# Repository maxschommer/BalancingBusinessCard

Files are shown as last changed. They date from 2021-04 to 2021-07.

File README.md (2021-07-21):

# business card

This is a persistence-of-vision (POV) business card, which is also NFC enabled
to aid in sharing contact information. POV is enabled by an accelerometer which
detects the end points of a swing of the card made by the user, and arranges
the letters to flash at the correct time in between two estimated end points
(the future end-point is guessed at by the length of the previous swing). Settings are changed by a capacitive sense button.

# Directory Structure

The firmare of the card is located in the `src` directory. The electrical
design files are in `design/business_card`. Images and other media are inside
`media`.

- [src](src/)
  - Contains the firmware of the card
- [design](design/)
  - Contains the KiCAD design files of the board
- [card_manufacturing](card_manufacturing/)
  - Contains python scripts used to generate GCODE to laser etch the aluminum top of the card.
- [media](media/)
  - Contains media (gifs, images, etc.)

# Building and Flashing Firmware

In order to flash the firmware, you must have the AVR toolchain installed.

`sudo apt-get install binutils gcc-avr avr-libc uisp avrdude flex byacc bison`

Then, navigate to the `src` directory and run `make` to build the object
file. In order to flash a business card, make sure to have your AVR programmer
plugged into your computer and connected to the board (and make sure the board
is appropriately powered!), then run

`make flash`

avrdude should say the the flash was successfull.

# Running manufacturing scripts

Some helper scripts exist to automate a lot of the manufacturing process for
customization. The scripts are specific to GRBL capable CNC machines (which
can laser etch). Scripts are written in python, and can be installed by
downloading the repository and running:

`pip install -e .`

Once the dependencies are installed, the scripts can be run from the root
directory, for example:

`python -m card_manufacturing.gcode_streamer`

## image_to_laser

This is a command line argument script which converts an image to an efficiently
rastered laser etcher GCODE path. It makes sure to utilize [laser mode](https://github.com/gnea/grbl/wiki/Grbl-v1.1-Laser-Mode) which
has been implemented in GRBL v1.1. The image is thresholded and the laser path
is binary (since the etching is all or nothing on coated aluminum). To get the
help for the script run:

`python -m card_manufacturing.image_to_laser -h`

## laser_calibration

This script generates a GCODE path to calibrate a CNC (with Z travel) with a
laser attachment. It progressively creates lines at different Z levels and
marks what the Z difference was on the line, so the user can identify the line
with the best marking and apply the appropriate offset for future etches. To
get the help for the script run:

`python -m card_manufacturing.laser_calibration -h`

## gcode_streamer

Finally, once GCODE is generated, the following script will stream the GCODE
to the CNC to run the part. To get the help for the script run:

`python -m card_manufacturing.gcode_streamer -h`

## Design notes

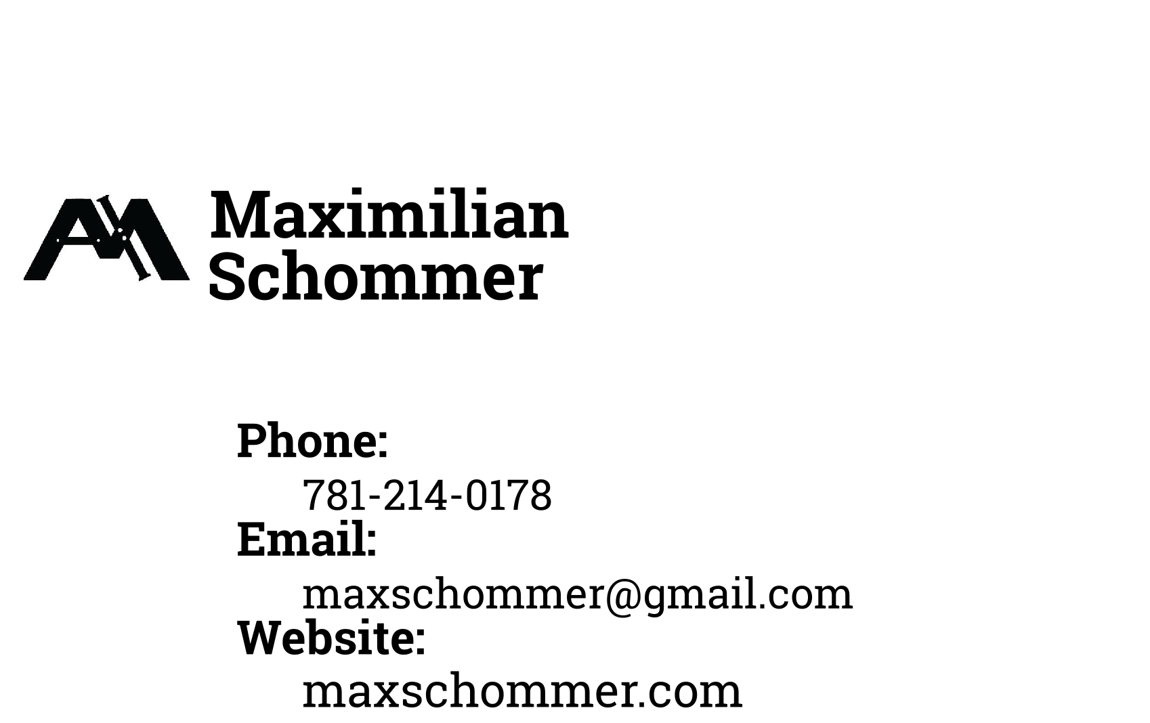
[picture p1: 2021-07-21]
media/max_card_laser.png

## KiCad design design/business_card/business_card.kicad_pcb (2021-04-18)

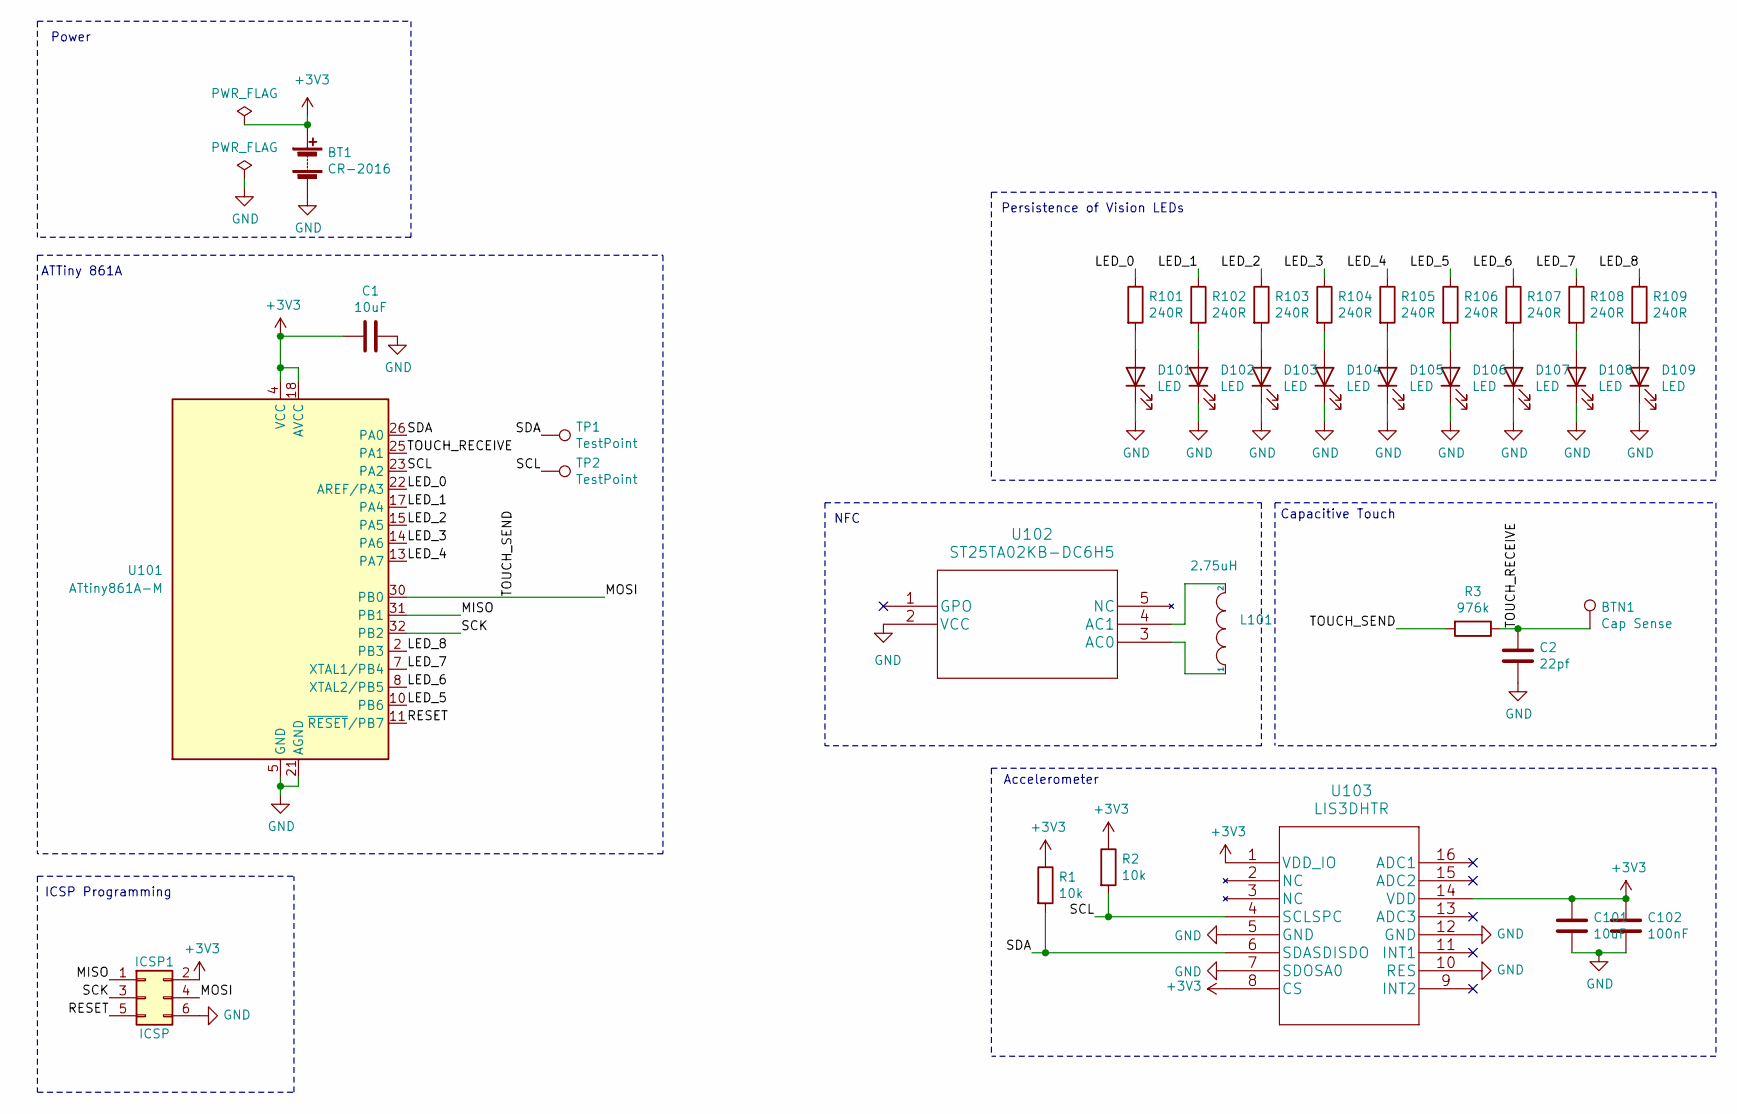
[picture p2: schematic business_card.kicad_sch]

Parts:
BT1: CR-2016; CR2016VP
BTN1: Cap Sense; CAP_TOUCH
C1, C101: 10uF; C_0805_2012Metric; Digikey 1276-6456-1-ND
C2: 22pf; C_0603_1608Metric; Digikey 732-7762-1-ND
C102: 100nF; C_0603_1608Metric; Digikey 311-1779-1-ND
D101, D102, D103, D104, D105, D106, D107, D108, D109: LED; LED_0603_1608Metric; Digikey 160-1183-1-ND
ICSP1: ICSP; PinHeader_2x03_P2.54mm_Vertical
L101: 2.75uH; Trace_Inductor_2_75uH
R1, R2: 10k; R_0603_1608Metric; Digikey 311-10KGRCT-ND
R3: 976k; R_0603_1608Metric; Digikey 311-976KHRCT-ND
R101, R102, R103, R104, R105, R106, R107, R108, R109: 240R; R_0603_1608Metric; Digikey 311-240GRCT-ND
TP1, TP2: TestPoint; TestPoint_Pad_D1.0mm
U101: ATtiny861A-M; QFN-32-1EP_5x5mm_P0.5mm_EP3.1x3.1mm; Digikey ATTINY861-15MZCT-ND
U102: ST25TA02KB-DC6H5; Digikey 497-19639-1-ND
U103: LIS3DHTR; Digikey 497-10613-1-ND

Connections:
+3V3: BT1.1 (+), C1.1, C101.1, C102.1, ICSP1.2, R1.1, R2.1, U101.4 (VCC), U101.18 (AVCC), U103.1 (VDD_IO), U103.8 (CS), U103.14 (VDD)
/LED_0: R101.1, U101.22 (AREF/PA3)
/LED_1: R102.1, U101.17 (PA4)
/LED_2: R103.1, U101.15 (PA5)
/LED_3: R104.1, U101.14 (PA6)
/LED_4: R105.1, U101.13 (PA7)
/LED_5: R106.1, U101.10 (PB6)
/LED_6: R107.1, U101.8 (XTAL2/PB5)
/LED_7: R108.1, U101.7 (XTAL1/PB4)
/LED_8: R109.1, U101.2 (PB3)
/MISO: ICSP1.1, U101.31 (PB1)
/MOSI: ICSP1.4, R3.2, U101.30 (PB0)
/RESET: ICSP1.5, U101.11 (~RESET~/PB7)
/SCK: ICSP1.3, U101.32 (PB2)
/SCL: R2.2, TP2.1, U101.23 (PA2), U103.4 (SCLSPC)
/SDA: R1.2, TP1.1, U101.26 (PA0), U103.6 (SDASDISDO)
/TOUCH_RECEIVE: BTN1.1, C2.1, R3.1, U101.25 (PA1)
GND: BT1.2 (-), C1.2, C2.2, C101.2, C102.2, D101.1 (K), D102.1 (K), D103.1 (K), D104.1 (K), D105.1 (K), D106.1 (K), D107.1 (K), D108.1 (K), D109.1 (K), ICSP1.6, U101.5 (GND), U101.21 (AGND), U101.33 (GND), U102.2 (VCC), U103.5 (GND), U103.7 (SDOSA0), U103.10 (RES), U103.12 (GND)
unnamed: D101.2 (A), R101.2
unnamed: D102.2 (A), R102.2
unnamed: D103.2 (A), R103.2
unnamed: D104.2 (A), R104.2
unnamed: D105.2 (A), R105.2
unnamed: D106.2 (A), R106.2
unnamed: D107.2 (A), R107.2
unnamed: D108.2 (A), R108.2
unnamed: D109.2 (A), R109.2
unnamed: L101.1, U102.3 (AC0)
unnamed: L101.2, U102.4 (AC1)

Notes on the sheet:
Power
ATTiny 861A
ICSP Programming
NFC
Accelerometer
Persistence of Vision LEDs
Capacitive Touch

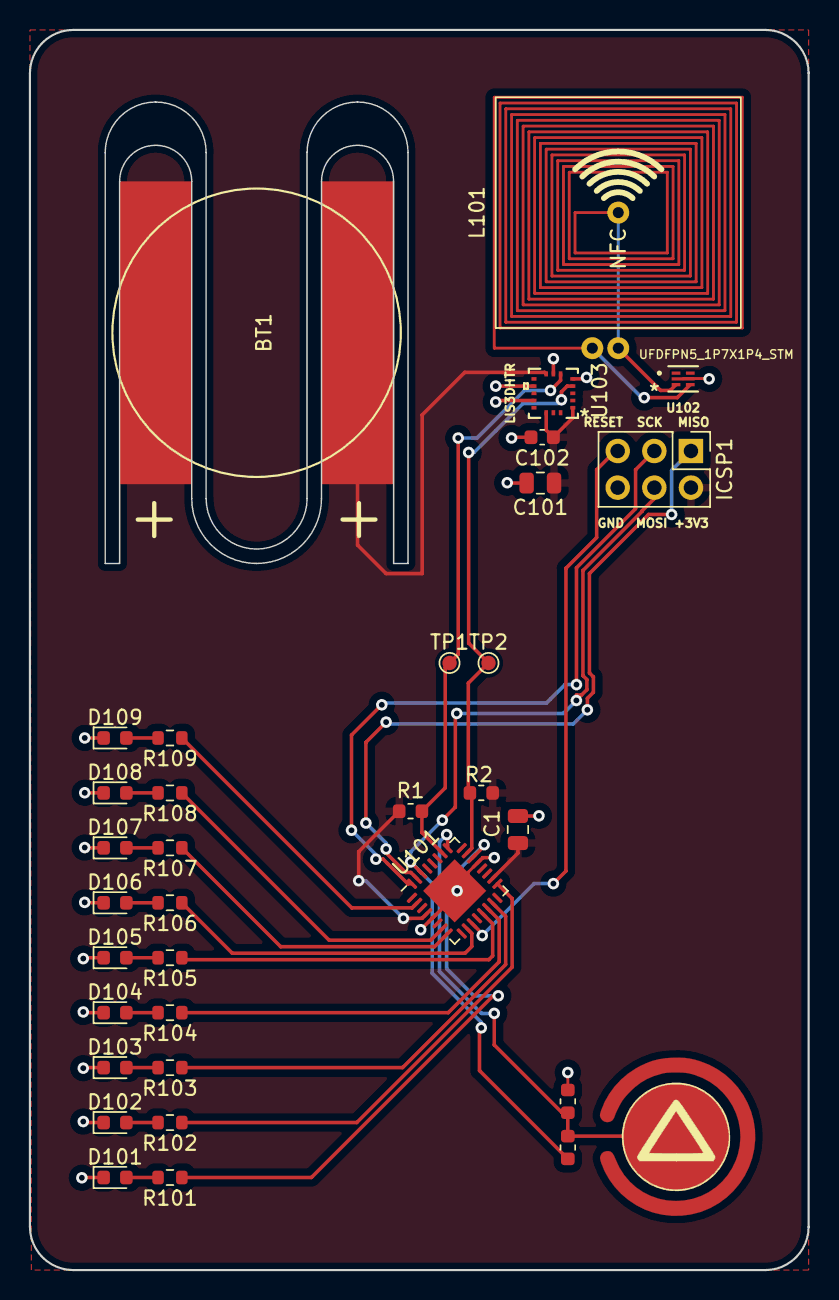
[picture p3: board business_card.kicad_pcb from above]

Board: 2 copper layers, 54.0 x 86.0 mm, 34 parts (0 on the bottom side), 29 nets.

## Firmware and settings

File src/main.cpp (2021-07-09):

/*
 * BalancingBusinessCard.cpp
 *
 * Created: 11/3/2018 4:36:13 PM
 * Author : mschommer
 */
#define F_CPU 2000000UL // 2 MHz for delay

#include <avr/io.h>
#include <stdio.h>
#include <math.h>
#include <util/delay.h>
#include <avr/interrupt.h>

#include "TinyWireM.h"
#include "USI_TWI_Master.h"

#include "alphabet.h"
#include "accelerometer_utils.h"
#include "touch_utils.h"

void Init_ACC()
{												   // Setup the LIS3DHTR
	lis3dhWriteByte(LIS3DH_CTRL_REG1, 0b10010111); // 1.344 kHz , No Low-power mode, all axes enabled
	lis3dhWriteByte(LIS3DH_CTRL_REG4, 0b00110000); // +-16g range, defaults otherwise
}

// Gets the current x-axis acceleration in m/s
float read_accel()
{
	int8_t raw = lis3dhReadByte(LIS3DH_OUT_X_H);
	return (int16_t(raw) << 2) * 0.004 * 9.8 * 8; // 4 milligees per digit in +-2g mode
}

void ShowLine(uint16_t line)
{
	PORTA = (PORTA & (~(0b000011111 << 3))) | (line & 0b000011111) << 3; // LED0, LED1, LED2, LED3, LED4
	PORTB = (PORTB & (~0b01111000)) |									 // Preserve TOUCH_SEND
			((line & 0b000100000) << 1) |								 // LED5
			((line & 0b001000000) >> 1) |								 // LED6
			((line & 0b010000000) >> 3) |								 // LED7
			((line & 0b100000000) >> 5);								 // LED8
}

// current_time returns the current time in increments of about 0.1 ms (1 tick), 0.000128s for 2MHz clock
// Must be called at least 30 times per second, or could lose count.
uint32_t current_time()
{
	static uint32_t timerOverflowCount = 0; // Each overflow count is 0.032768s for 2MHz clock

	// Record total time since start
	if ((TIFR & (1 << TOV0)) == (1 << TOV0)) // check if overflow flag is set
	{
		TIFR = 1 << TOV0; //clear timer1 overflow flag
		timerOverflowCount++;
	}
	return TCNT0L + 256 * timerOverflowCount; // total time since start of uC
}

// Returns 1 if maxima detected, -1 if minima detected, or 0
int8_t detect_edge(uint32_t t)
{
	// TODO: switch to a filter?
	const float DEBOUNCE_THRESH = 4.0; // m/s^2

	static int8_t dir = 1; // Start looking for a max

	static float min_detected = 9999999;

	float val = read_accel() * dir;

	if (val < min_detected)
	{
		min_detected = val;
	}

	if (val > min_detected + DEBOUNCE_THRESH)
	{
		// Edge detected
		min_detected = 9999999;
		dir *= -1;
		return dir;
	}

	return 0;
}

int main()
{
	// Configuring ATTiny

	CLKPR = 1 << CLKPCE;
	CLKPR = 1 << CLKPS1; // Set clock division to 4

	TCCR0B = 1 << CS02; // Divide clock by 256

	USICR = 1 << USIWM1; // Enable Two-Wire mode of USI register

	DDRB = 0b01111011; // Set LEDs on port B as output, and the touch send PB0
	DDRA = 0b11111000; // Set LEDs on port A as output
	TinyWireM.begin(); // initialize I2C lib

	Init_ACC();

	// Message Display Parameters
	char *messages[2];
	messages[0] = "MAX";
	messages[1] = "ERIC";

	int message_idx = 0;
	char *message = messages[message_idx];                  // Message to display
	int kerning = 2;					// Space between letters, in bars
	const float before_message_frac = 0.2;                  // Target fraction of cycle waiting before display

	// Generate Flash Pattern
	FlashPattern flashPattern;
	convertString(message, kerning, &flashPattern);
	long double timeToWait;

	// Variable Initializations
	uint32_t lastLeftEdgeTime = current_time();             // Time that the last acceleration peak was detected
	uint32_t estimated_period = 10000;			// In ticks, time to sweep right
	uint32_t message_start_time = 0;
	uint32_t message_end_time = 1;
	uint32_t message_duration = 1;
	int8_t dir = 1; // 1 if moving right, -1 if moving left

	TouchSense touch;
	touch.threshold = 10;

	while (1)
	{
		// Detect the left edge
		uint32_t t = current_time();

		float frac_message = (t - message_start_time) / float(message_end_time - message_start_time);

		// Display
		if (frac_message >= 0.0 && frac_message < 1.0)
		{
			size_t currentIndex = frac_message * flashPattern.length;

			if (dir > 0)
			{
				currentIndex = flashPattern.length - currentIndex - 1;
			}

			ShowLine(flashPattern.data[currentIndex]);
		}
		else
		{
			ShowLine(0);

			// Check for and handle a button press
			if (touch.just_pressed())
			{
				int ms = 0;
				while (ms < 1000){
					ShowLine(message_idx);
					_delay_ms(10);
					ms += 10;
					if (touch.just_pressed()){
						message_idx++;
						ms = 0;
					}
				}
				message = messages[message_idx % (sizeof(messages) / sizeof(messages[0]))];
				convertString(message, kerning, &flashPattern);
			}

			// Check for an edge, update variables if found
			int8_t edge = detect_edge(t);

			if (edge == -1)
			{
				// Detected a left edge
				dir = edge;
				lastLeftEdgeTime = t;

				message_start_time = lastLeftEdgeTime + (estimated_period * before_message_frac);
				message_end_time = lastLeftEdgeTime + (estimated_period * (1 - before_message_frac));
				message_duration = message_end_time - message_start_time;
			}
			else if (edge == 1)
			{
				// Detected a right edge
				dir = edge;

				// Estimate the period
				estimated_period = t - lastLeftEdgeTime;
				if (estimated_period > 10000)
				{
					estimated_period = 10000;
				}

				uint32_t detected_delay = t - message_end_time;
				if (detected_delay > 10000 || detected_delay < 0)
				{
					// Do not display a message
					message_start_time = 0;
					message_end_time = 1;
				}
				else
				{
					message_start_time = t + detected_delay;
					message_end_time = message_start_time + message_duration;
				}
			}
		}
	}
}

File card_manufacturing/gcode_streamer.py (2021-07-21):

import time
from typing import List
from functools import partial
import signal
import sys
import re
import argparse
from pathlib import Path
import logging
import plac
import serial

# Uncomment the line below to mock the serial port
# import card_manufacturing.fake_serial as serial

RX_BUFFER_SIZE = 128


# Global variables
g_consumed = 0
g_error = 0
g_sent = 0
g_buffer: List[int] = []
is_absolute = False


def clean(conn: serial.Serial):
    """Clean the serial port from 

    Args:
        conn (serial.Serial): The serial connection to clean.
    """
    global g_consumed
    global g_error
    global g_sent
    global g_buffer
    while g_sent > g_consumed:
        grbl_resp = conn.readline().strip().decode()
        # Debug response
        if grbl_resp.find('ok') < 0 and grbl_resp.find('error') < 0:
            logging.info(f"MSG: '{grbl_resp}'")
        else:  # Interpreted GCode response
            if grbl_resp.find('error') >= 0:
                logging.warning(f"GCode Error: {grbl_resp}")
                g_error += 1
            g_consumed += 1
            logging.info(f"REC<{g_consumed}: '{grbl_resp}'")
            del g_buffer[0]


def send_and_log(conn, data):
    if isinstance(data, str):
        data = data.encode()
    global g_consumed
    conn.write(data)
    resp = conn.readline().decode()
    logging.info(f"REC<{g_consumed}: '{resp}'")


def signal_handler(conn, signal, frame):
    global g_consumed
    global g_error
    global g_sent
    global is_absolute
    clean(conn)

    logging.info("Returning Home")
    if not is_absolute:
        send_and_log(conn, "G90\n".encode())
    send_and_log(conn, "G0X0Y0Z0\n".encode())
    send_and_log(conn, "M5\n")
    send_and_log(conn, "$32=0\n")
    sys.exit(0)


@plac.pos('file', 'the gcode file to stream', type=Path)
@plac.annotations(
    device_file=(
        'the serial device path'
    ),
    baud_rate=(
        'the baud rate of the device to stream to',
        'option', 'br', int),
    zero_cnc=(
        'zero the CNC to cut from it\'s current position.',
        'flag', 'zc'
    ),
    log_level=(
        'the log level for the program. Options are "DEBUG",'
        '"INFO", "WARNING", "ERROR", and "CRITICAL".', 'option',
        'll', str, ["DEBUG", "INFO", "WARNING", "ERROR",
                    "CRITICAL"])
)
def gcode_streamer(
    file: Path,
    device_file: str,
    baud_rate: int = 115200,
    zero_cnc: bool = False,
    log_level: str = "INFO"
):
    """Stream GCODE to a GRBL device using an aggressive streaming protocol
    which attempts to keep the buffer on the machine as full as possible.
    """
    global g_consumed
    global g_error
    global g_sent
    global g_buffer
    global is_absolute
    logging.basicConfig()
    logging.getLogger().setLevel(log_level)

    with serial.Serial(device_file, baud_rate) as s_conn:
        signal.signal(signal.SIGINT, partial(signal_handler, s_conn))

        logging.info("Initializing grbl")
        s_conn.write("\r\n\r\n".encode())
        resp = s_conn.readline()

        time.sleep(2)
        s_conn.flushInput()
        s_conn.write("$X\n".encode())
        resp = s_conn.readline().strip().decode()
        logging.info(f"Unlocked: {resp}")

        if zero_cnc:
            send_and_log(s_conn, "G92X0Y0Z0\n")
            send_and_log(s_conn, "G10L20P1X0Y0Z0\n")
            logging.info(f"Zeroed: {resp}")

        t_start = time.time()
        with open(file, mode='r') as f:

            for i, line in enumerate(f):
                line = re.sub('\s|\(.*?\)', '', line).upper()

                g_buffer.append(len(line))

                # If the buffer is full, wait for a response
                while sum(g_buffer) >= RX_BUFFER_SIZE - 1 | s_conn.inWaiting():
                    grbl_resp = s_conn.readline().strip().decode()

                    # Debug response
                    if grbl_resp.find('ok') < 0 and grbl_resp.find('error') < 0:
                        logging.info(f"MSG: '{grbl_resp}'")
                    else:  # Interpreted GCode response
                        if grbl_resp.find('error') >= 0:
                            logging.warning(f"GCode Error: {grbl_resp}")
                            g_error += 1
                        g_consumed += 1
                        logging.info(f"REC<{g_consumed}: '{grbl_resp}'")
                        del g_buffer[0]

                s_conn.write(f'{line}\n'.encode())
                if line.find('G90') >= 0:
                    is_absolute = True
                if line.find('G91') >= 0:
                    is_absolute = False
                g_sent = i
                logging.info(f"SND>{i}: '{line}'")

            clean(s_conn)

        # We have no way of knowing when gcode is done being executed, so we just
        # wait for a bit. Optionally, we could wait for user input, but this
        # is more automated.
        time.sleep(5)
        t_end = time.time()
        logging.info("G-code streaming finished!")
        logging.info(f"Time elapsed: {t_end - t_start}")


if __name__ == '__main__':
    plac.call(gcode_streamer)

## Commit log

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2018-10-21 Made module sheets
    [BalancingBusinessCard.kicad_pcb, BalancingBusinessCard.sch, lightModule.sch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]
2018-10-21 Made a part
    [BalancingBusinessCard.sch, lightModule.sch, motorModule.sch]
2018-10-21 Fixed reference
    [BalancingBusinessCard.sch, lightModule.sch, motorModule.sch]
2018-10-21 pulling ref change
    [motorModule.sch]
2018-10-21 Made more parts
    [BalancingBusinessCard.sch, lightModule.sch, motorModule.sch]
2018-10-21 Added ICSP header
    [BalancingBusinessCard.sch, lightModule.sch, motorModule.sch]
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2018-10-21 Making filter
    [BalancingBusinessCard.sch]
2018-10-21 Added IMU
    [BalancingBusinessCard.sch, LIS3DHTR.sch, lightModule.sch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]
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2018-10-21 Wired up LEDs
    [BalancingBusinessCard.sch, LIS3DHTR.sch]
2018-10-21 scrapped an inductor filter
    [BalancingBusinessCard.sch, LIS3DHTR.sch]
2018-10-21 Added power electronics for main chip
    [BalancingBusinessCard.sch]
2018-10-21 Fixed stuff
    [BalancingBusinessCard.sch]
2018-10-21 Assigned numbers
    [BalancingBusinessCard.sch, LIS3DHTR.sch, lightModule.sch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]
2018-10-21 Footprint assignment
    [BalancingBusinessCard.sch, LIS3DHTR.sch, lightModule.sch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]
2018-10-21 Added regulator
    [BalancingBusinessCard.sch, LIS3DHTR.sch, ft550.sch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]
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2018-10-21 Got Schematic CRC running
    [BalancingBusinessCard.sch, LIS3DHTR.sch, ft550.sch]
2018-10-21 Final schematic assignments
    [BalancingBusinessCard.sch, ft550.sch, motorModule.sch]
2018-10-21 Layin out
    [BalancingBusinessCard.kicad_pcb, _saved_BalancingBusinessCard.sch]
2018-10-21 Made battery and circle centered and added edge cuts
    [BalancingBusinessCard.kicad_pcb, BalancingBusinessCard.sch, _saved_BalancingBusinessCard.sch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]
2018-10-21 Moved stuff
    [BalancingBusinessCard.kicad_pcb]
2018-10-21 Routed IMU and Regulator
    [BalancingBusinessCard.kicad_pcb]
2018-10-21 messiest of merges
    [BalancingBusinessCard.kicad_pcb]
2018-10-21 More routing on motor driver
    [BalancingBusinessCard.kicad_pcb]
2018-10-21 Finished MCU
    [BalancingBusinessCard.kicad_pcb]
2018-10-21 Wired ground
    [BalancingBusinessCard.kicad_pcb]
2018-10-21 Work on pads
    [BalancingBusinessCard.kicad_pcb]
2018-10-21 Manual cleanup
    [BalancingBusinessCard.kicad_pcb]
2018-10-21 Automatic cleanup
    [BalancingBusinessCard.kicad_pcb]
2018-10-21 Did text
    [BalancingBusinessCard.kicad_pcb]
2018-10-21 Fixed routing
    [BalancingBusinessCard.kicad_pcb]
2018-10-21 Passed DRC
    [BalancingBusinessCard.kicad_pcb]
2018-10-21 Added ground pour
    [BalancingBusinessCard.kicad_pcb]
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2018-10-21 Final from Saturday
    [BalancingBusinessCard.kicad_pcb]
2018-10-21 Made mousebites and improved battery tab
    [BalancingBusinessCard.kicad_pcb]
2018-11-12 Programming starting
    [BalancingBusinessCard-B.Adhes.gbr, BalancingBusinessCard-B.Cu.gbr, BalancingBusinessCard-B.Mask.gbr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]
2018-11-12 BOM stuff
    [BalancingBusinessCard.csv, BalancingBusinessCard.ods]
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2018-12-07 Moded power schematic for fixed version
    [main.cpp]
2018-12-10 Completed Lights board schematic
    [3V3Regulator.sch, BalancingBusinessCardLights.kicad_pcb, BalancingBusinessCardLights.sch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]
2018-12-10 Finished light board layout and silkscreen design
    [3V3Regulator.sch, BalancingBusinessCardLights.kicad_pcb, BalancingBusinessCardLights.sch]
2018-12-14 Rev2 Shipped
    [BalancingBusinessCard-B.Cu.gbr, BalancingBusinessCard-B.Mask.gbr, BalancingBusinessCard-F.Cu.gbr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]
2019-01-09 Made working tilt switch code
    [3V3Regulator.sch, BalancingBusinessCardLights.sch]
2019-01-12 broken, getting i2c to work
    [USI_TWI_Master.h, lis3dh_reg.c, main.cpp]
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2019-02-20 Revert "Working 9-bit display"
    This reverts commit 6f789adadc6e6a2334bb884a12fdf926cae32f34.
    # Conflicts:
    # src/main.cpp
    [main.cpp]
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2019-03-05 Minor work on code stuff
    [BalancingBusinessCardLights.csv]
2019-03-05 Began v3 board design
    [3V3Regulator.sch, BalancingBusinessCardLights.kicad_pcb, BalancingBusinessCardLights.sch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]
2019-03-05 Basic layout for v3
    [BalancingBusinessCardLights.kicad_pcb]
2019-03-05 Final changes from the night
    [BalancingBusinessCardLights.kicad_pcb]
2019-03-09 Added explicit routing for most ground and power wires
    [BalancingBusinessCardLights.kicad_pcb]
2019-03-09 Moved all components to top half of board
    [BalancingBusinessCardLights.kicad_pcb]
2019-03-12 Updated ground pour to avoid thermal relief
    [BalancingBusinessCardLights.kicad_pcb]
2019-03-12 Minor board tweaks
    [BalancingBusinessCardLights.kicad_pcb]
2019-03-12 Reverted layout to old one for text placement
    [BalancingBusinessCardLights.kicad_pcb]
2019-03-12 Added new components
    [BalancingBusinessCardLights.kicad_pcb]
2019-03-12 Right Stuff
    [BalancingBusinessCardLights.sch]
2019-03-12 Made touch sense cap
    [3V3Regulator.sch, BalancingBusinessCardLights.sch, LIS3DHTR.sch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]
2019-03-12 Fixed .gitignore
    [BalancingBusinessCardLights-B.Adhes.gbr, BalancingBusinessCardLights-B.Cu.gbr, BalancingBusinessCardLights-B.Fab.gbr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]
2019-03-12 Fixing stuff
    [capTouch.dxf]
2019-03-12 Made custom test point symbol
    [BalancingBusinessCardLights.sch]
2019-03-12 Got a better test point
    [BalancingBusinessCardLights.sch]
2019-03-12 Updated orientation of button
    [BalancingBusinessCardLights.kicad_pcb]
2019-03-12 Cleaned up fills
    [3V3Regulator.sch, BalancingBusinessCardLights.kicad_pcb, BalancingBusinessCardLights.sch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]
2019-03-31 Minor DRC fixes
    [BalancingBusinessCardLights.kicad_pcb]
2019-03-31 Updated BOM
    [BalancingBusinessCardLights.csv]
2019-03-31 Updated names
    [3V3Regulator.sch, BalancingBusinessCardLights.csv, BalancingBusinessCardLights.kicad_pcb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]
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2021-02-11 Cleaned repo and reorganized business card for new dimensions and NFC
    [LIS3DHTR.kicad_sch, business_card.kicad_pcb, business_card.kicad_sch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]
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2021-02-11 Deleted more spurious files and fixed design so it builds properly
    [LIS3DHTR.kicad_sch, business_card.kicad_pcb, ft550.sch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]
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2021-04-18 Deleted kicad session file, tested image_to_laser
    [business_card.kicad_pcb, business_card.kicad_sch]
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

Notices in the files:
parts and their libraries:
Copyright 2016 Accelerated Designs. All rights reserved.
